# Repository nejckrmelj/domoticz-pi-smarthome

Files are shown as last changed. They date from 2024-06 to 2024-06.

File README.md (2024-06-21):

# Smart Home with Domoticz and Raspberry Pi

## Introduction

This repository is a software and hardware source for a smart home project I was working on during one month of practical training at Erasmus+, at Gut Wehlitz in Schkeuditz, Leipzig, Germany. My mentor Aran Talboys gave me a project to control the relay board with Raspberry Pi and Domoticz. The final version works through MQTT. Raspberry uses docker compose to run three services: Mosquitto MQTT broker, Domoticz smart home system and a python hardware client. Hardware client listens on Domoticz's topic and controls the GPIOs which are connected to relays on the relay board. In the current version GPIOs are not fully synced with Domoticz - if GPIO is changed by some other program, change is not reflected by the hardware client.

## Technologies Used

- **Domoticz** (smart home system)
- **MQTT**
- **Docker**

## Local Setup

Before you start, you need to have a remote GPIO access enabled on your Raspberry Pi (enable it in `sudo raspi-config` settings and with `sudo systemctl enable pigpiod` on your Pi).

To run this repo locally, follow these steps:

1. Clone repository `git clone [repo url]`

2. Move to the software directory `cd software`

3. Copy .env.template file to the .env file and edit variables

4. Build and run app with `docker compose build` and `docker compose up`

5. Go to [http://localhost:8080/](http://localhost:8080/) or [https://localhost:443/](https://localhost:443/)

6. On Domoticz add hardware with type _MQTT Client Gateway with LAN interface_, remote address _mosquitto_ and username and password from you .env file

7. Add new hardware for every useful GPIO on the Raspberry Pi with name _GPIO [pin number]_ and type _Dummy (Does nothing, use for virtual switches only_

8. Add switches with hardware _GPIO [pin number]_ with any type and name

### Clone Repo With Git Sparse Checkout

To clone only specific folder (e.g. on the Rapsberry Pi you only need a software folder) use git sparse: checkout

1. Init repository localy with `git init` and `git remote add origin [repo url]`

2. Init git sparse checkout `git sparse-checkout init --cone`

3. Specify folder to pull `git sparse-checkout set [folder name]`

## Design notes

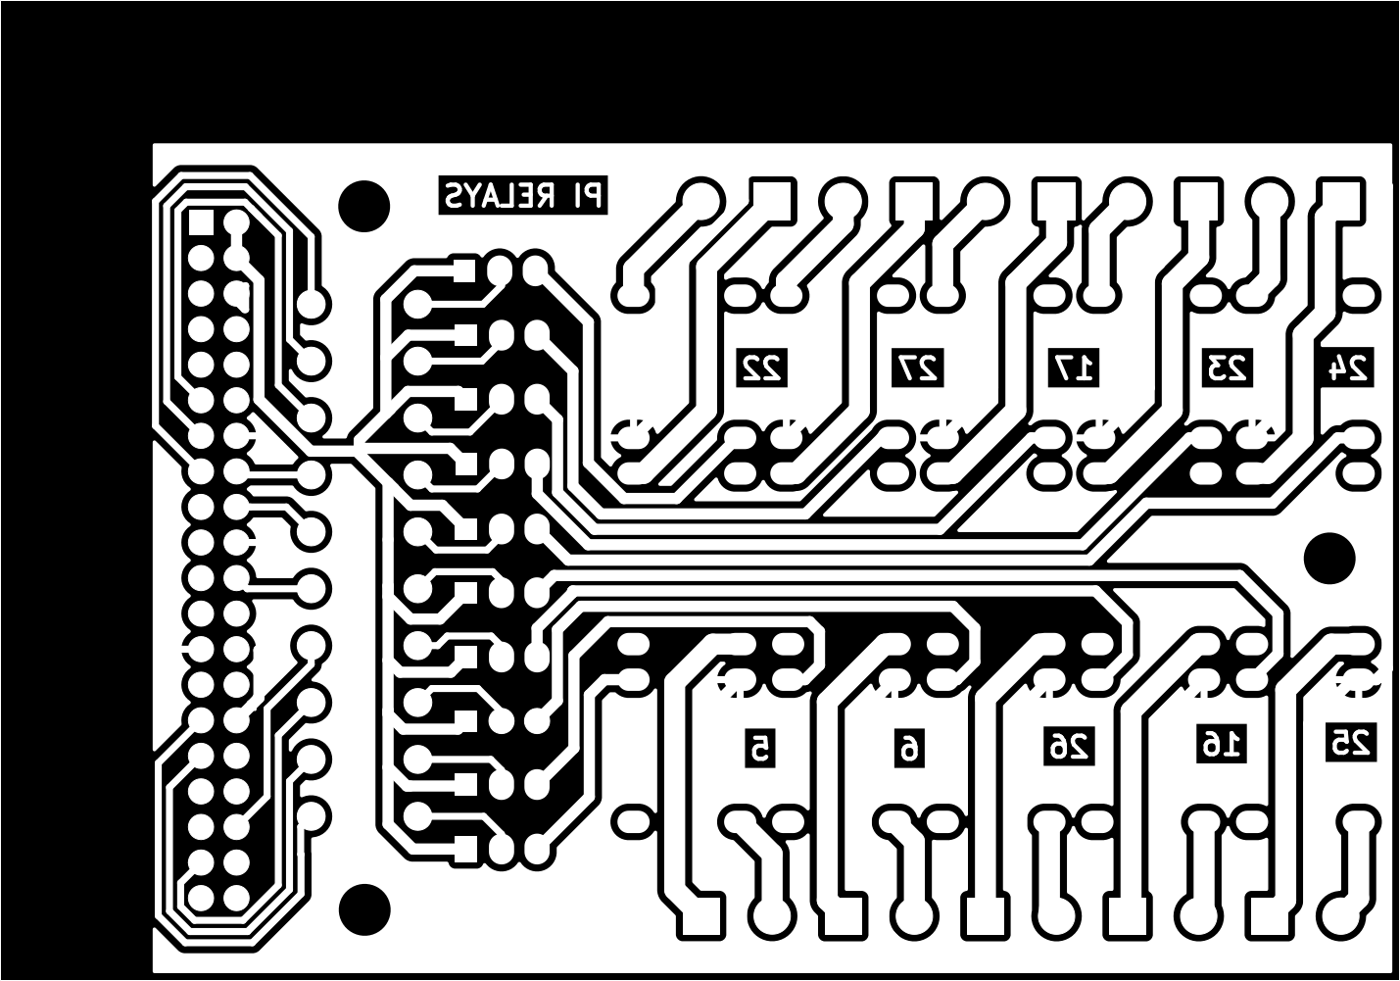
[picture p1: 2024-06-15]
hardware/pi-relay-board/production/relay-board-laser-4.png

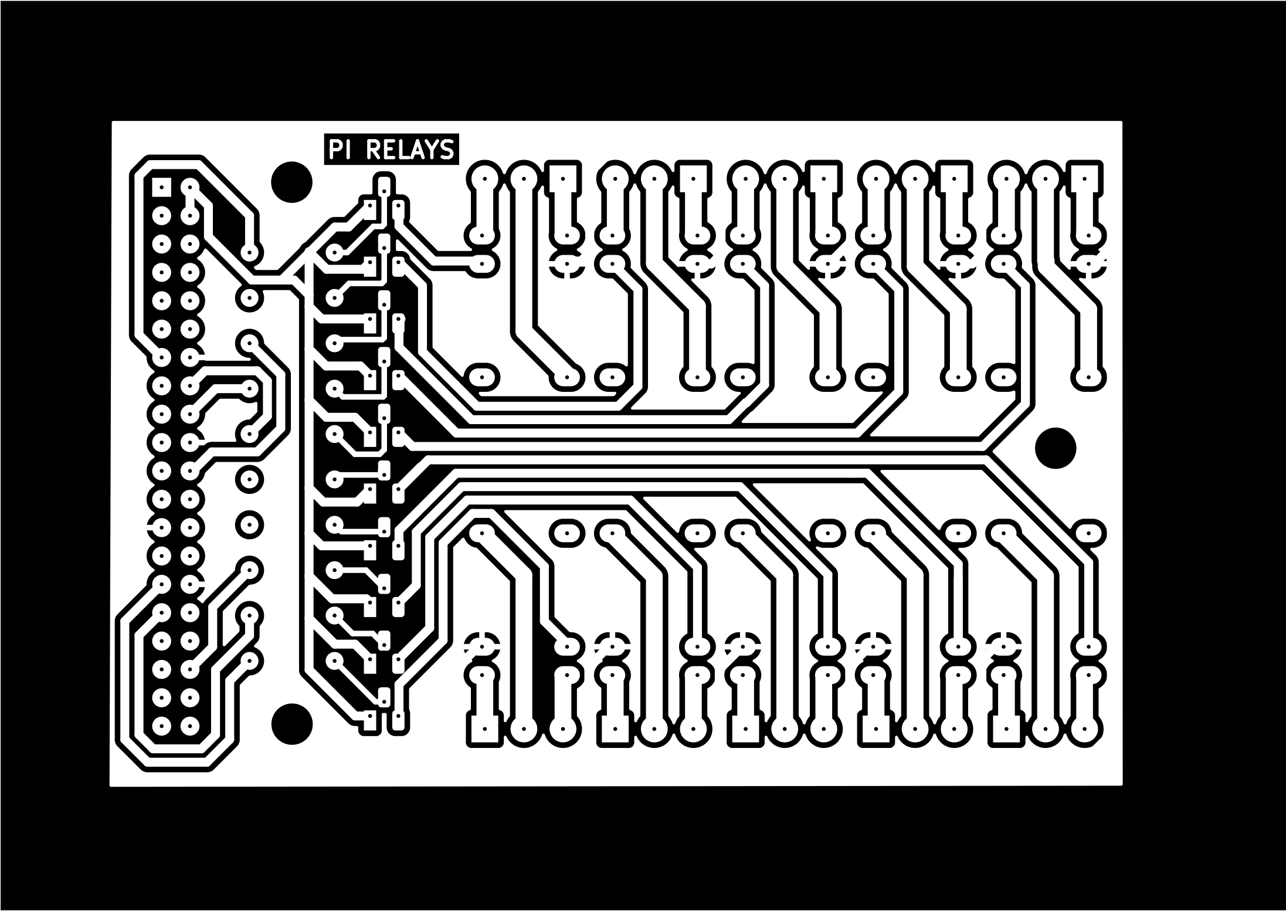
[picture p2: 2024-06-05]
hardware/pi-relay-board/production/relay-board-laser-2.png

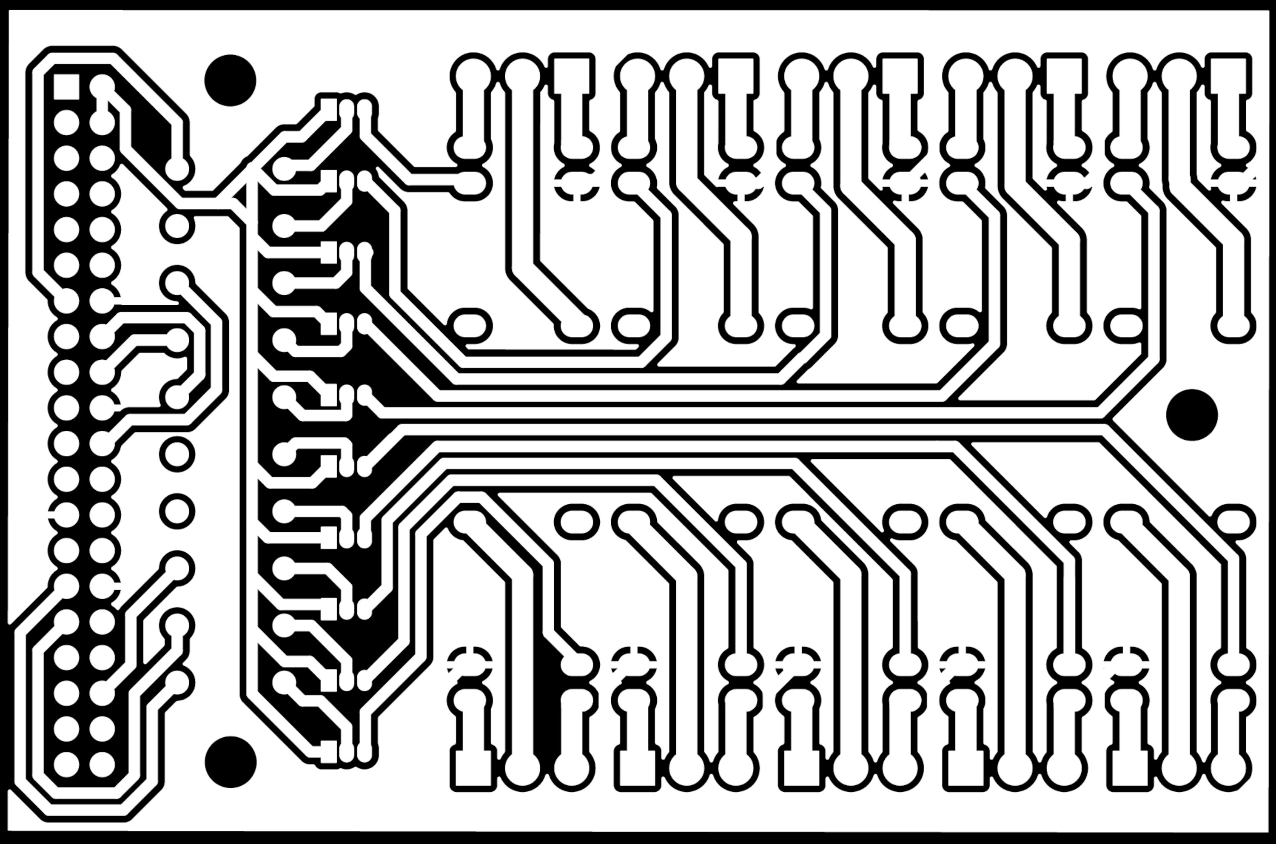
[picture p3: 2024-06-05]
hardware/pi-relay-board/production/relay-board-laser.png

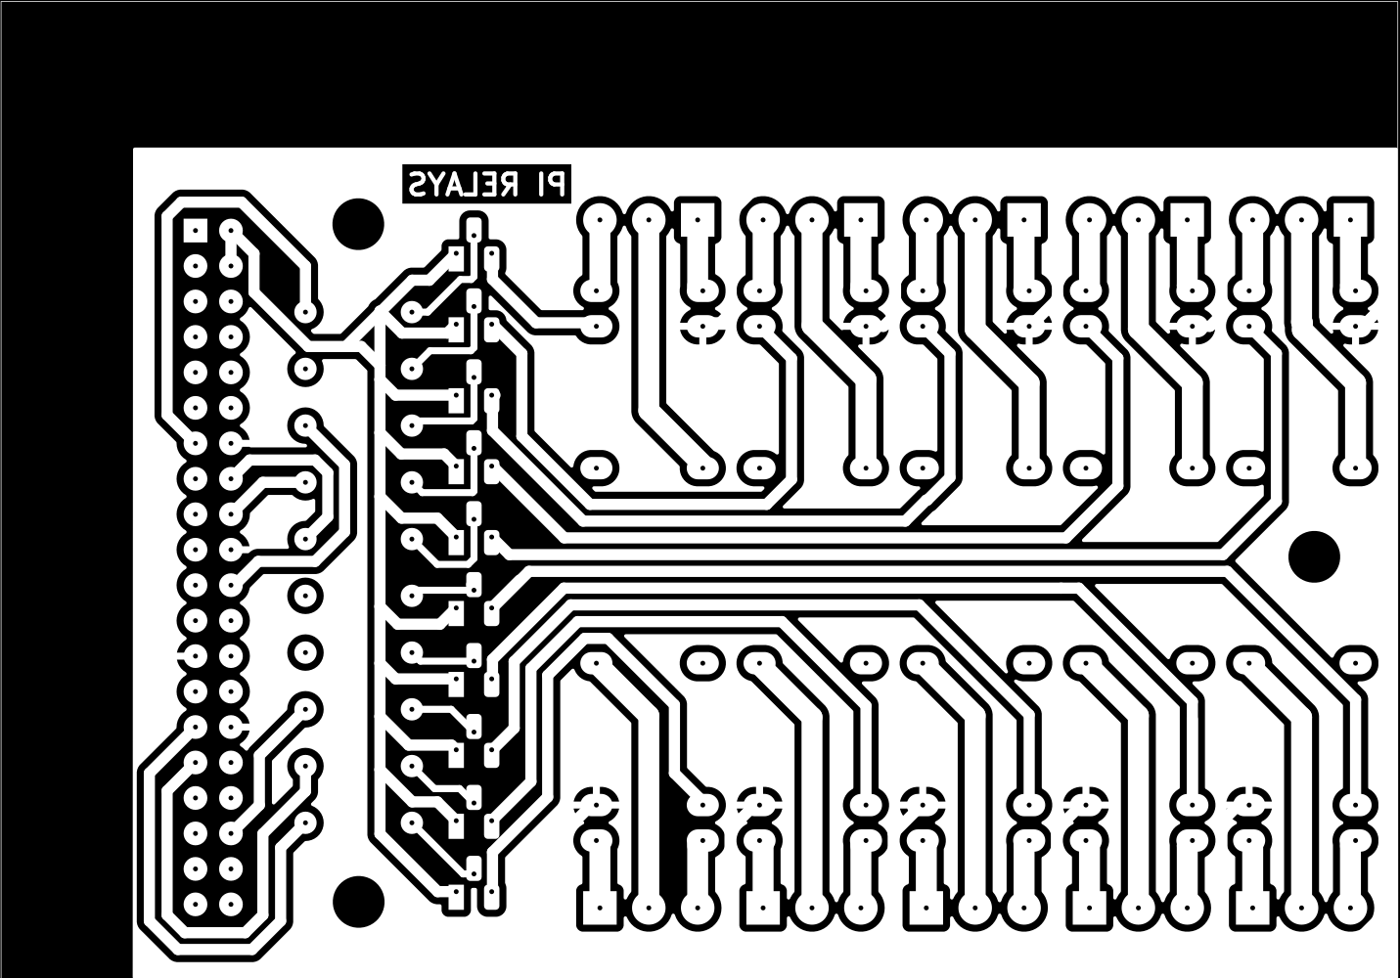
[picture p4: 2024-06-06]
hardware/pi-relay-board/production/relay-board-laser-3.png

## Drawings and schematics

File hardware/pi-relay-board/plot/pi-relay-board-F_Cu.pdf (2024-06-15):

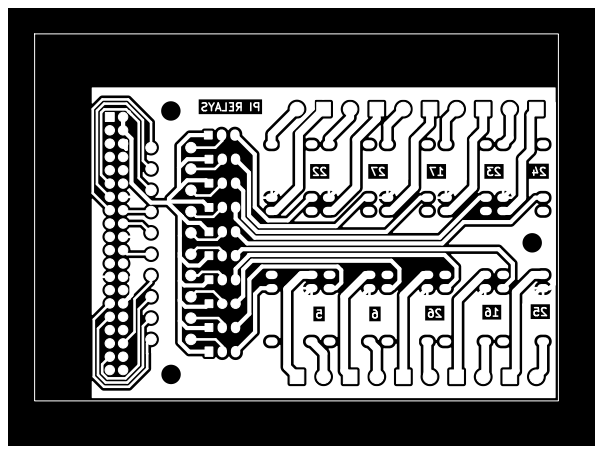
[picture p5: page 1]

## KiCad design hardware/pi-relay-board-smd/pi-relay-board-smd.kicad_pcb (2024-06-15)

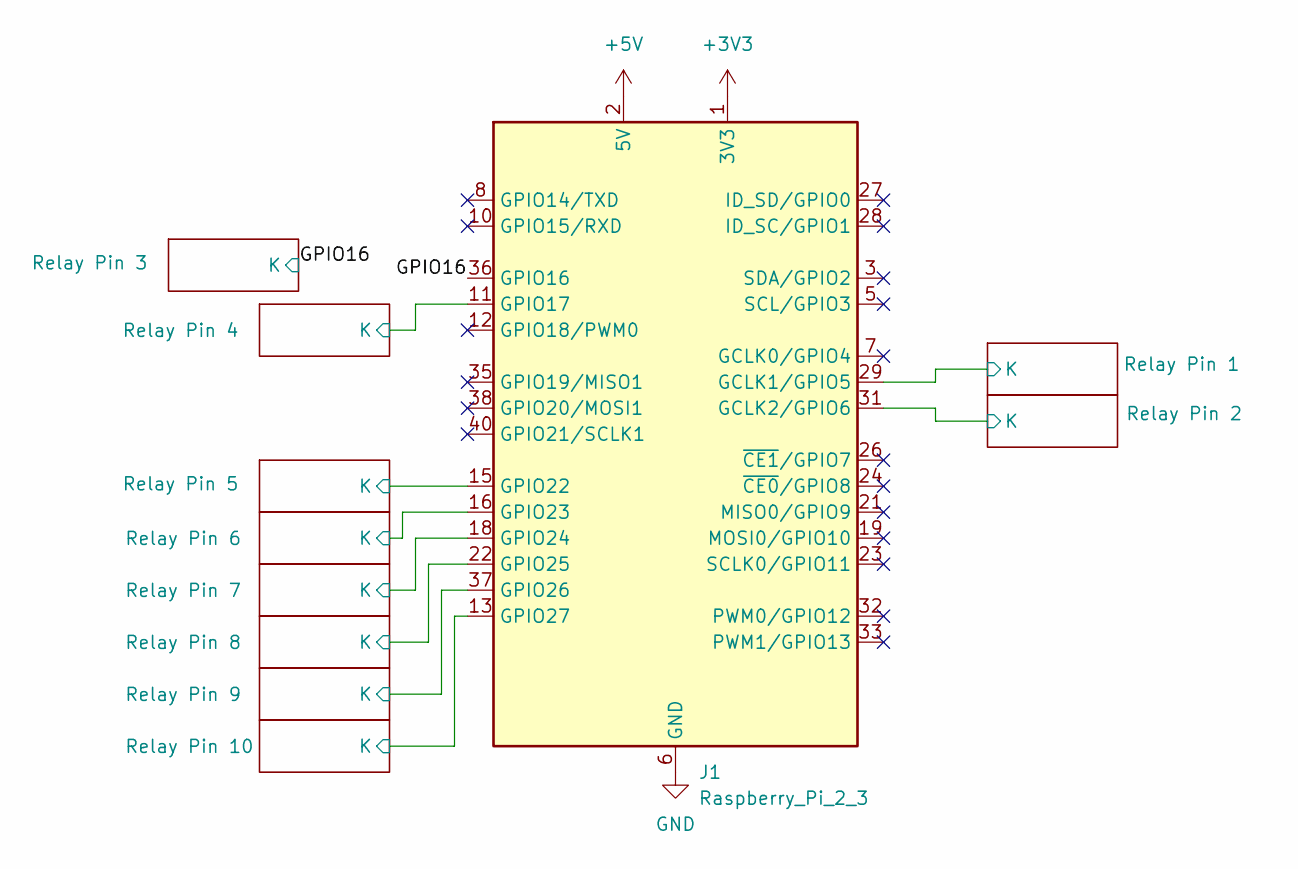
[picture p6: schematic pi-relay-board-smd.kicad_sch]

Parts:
J1: Raspberry_Pi_2_3; PinHeader_2x20_P2.54mm_Vertical_SMD

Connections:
+3V3: J1.1 (3V3), J1.17 (3V3)
+5V: J1.2 (5V), J1.4 (5V); also elsewhere on the board
/GPIO16: J1.36 (GPIO16); also elsewhere on the board
/Relay Pin 1/K: J1.29 (GCLK1/GPIO5); also elsewhere on the board
/Relay Pin 2/K: J1.31 (GCLK2/GPIO6); also elsewhere on the board
/Relay Pin 4/K: J1.11 (GPIO17); also elsewhere on the board
/Relay Pin 5/K: J1.15 (GPIO22); also elsewhere on the board
/Relay Pin 6/K: J1.16 (GPIO23); also elsewhere on the board
/Relay Pin 7/K: J1.18 (GPIO24); also elsewhere on the board
/Relay Pin 8/K: J1.22 (GPIO25); also elsewhere on the board
/Relay Pin 9/K: J1.37 (GPIO26); also elsewhere on the board
/Relay Pin 10/K: J1.13 (GPIO27); also elsewhere on the board
GND: J1.6 (GND), J1.9 (GND), J1.14 (GND), J1.20 (GND), J1.25 (GND), J1.30 (GND), J1.34 (GND), J1.39 (GND); also elsewhere on the board

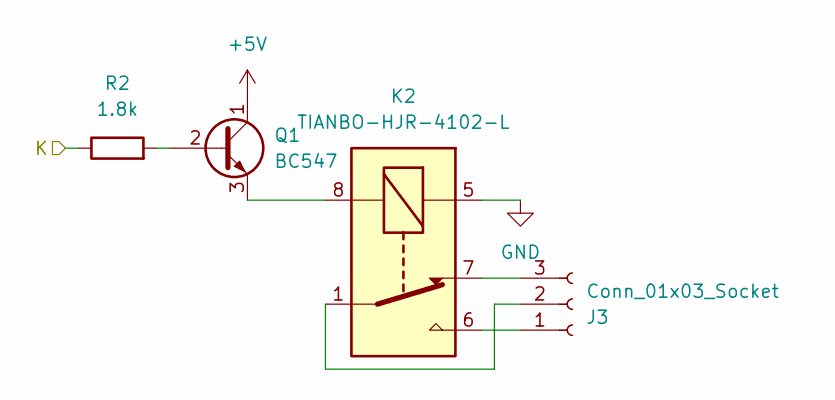
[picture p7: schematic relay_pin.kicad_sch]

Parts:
J3: Conn_01x03_Socket; TerminalBlock_Phoenix_PT-1,5-3-3.5-H_1x03_P3.50mm_Horizontal
K2: TIANBO-HJR-4102-L; Relay_SPDT_HJR-4102
Q1: BC547; SOT-23
R2: 1.8k; R_0805_2012Metric_Pad1.20x1.40mm_HandSolder

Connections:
+5V: Q1.1 (C); also elsewhere on the board
/Relay Pin 2/K: R2.1; also elsewhere on the board
GND: K2.5; also elsewhere on the board
unnamed: J3.1, K2.6
unnamed: J3.2, K2.1
unnamed: J3.3, K2.7
unnamed: Q1.2 (B), R2.2
unnamed: K2.8, Q1.3 (E)

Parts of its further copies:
J2, J4, J5, J6, J7, J8, J9, J10, J11: Conn_01x03_Socket; TerminalBlock_Phoenix_PT-1,5-3-3.5-H_1x03_P3.50mm_Horizontal
K1, K3, K4, K5, K6, K7, K8, K9, K10: TIANBO-HJR-4102-L; Relay_SPDT_HJR-4102
Q2, Q3, Q4, Q5, Q6, Q7, Q8, Q9, Q10: BC547; SOT-23
R1, R3, R4, R5, R6, R7, R8, R9, R10: 1.8k; R_0805_2012Metric_Pad1.20x1.40mm_HandSolder

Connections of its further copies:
+5V: Q2.1 (C), Q3.1 (C), Q4.1 (C), Q5.1 (C), Q6.1 (C), Q7.1 (C), Q8.1 (C), Q9.1 (C), Q10.1 (C); also elsewhere on the board
/GPIO16: R3.1; also elsewhere on the board
/Relay Pin 1/K: R1.1; also elsewhere on the board
/Relay Pin 4/K: R4.1; also elsewhere on the board
/Relay Pin 5/K: R5.1; also elsewhere on the board
/Relay Pin 6/K: R6.1; also elsewhere on the board
/Relay Pin 7/K: R7.1; also elsewhere on the board
/Relay Pin 8/K: R8.1; also elsewhere on the board
/Relay Pin 9/K: R9.1; also elsewhere on the board
/Relay Pin 10/K: R10.1; also elsewhere on the board
GND: K1.5, K3.5, K4.5, K5.5, K6.5, K7.5, K8.5, K9.5, K10.5; also elsewhere on the board
unnamed: J2.1, K1.6
unnamed: J2.2, K1.1
unnamed: J2.3, K1.7
unnamed: J4.1, K3.6
unnamed: J4.2, K3.1
unnamed: J4.3, K3.7
unnamed: J5.1, K4.6
unnamed: J5.2, K4.1
unnamed: J5.3, K4.7
unnamed: J6.1, K5.6
unnamed: J6.2, K5.1
unnamed: J6.3, K5.7
unnamed: J7.1, K6.6
unnamed: J7.2, K6.1
unnamed: J7.3, K6.7
unnamed: J8.1, K7.6
unnamed: J8.2, K7.1
unnamed: J8.3, K7.7
unnamed: J9.1, K8.6
unnamed: J9.2, K8.1
unnamed: J9.3, K8.7
unnamed: J10.1, K9.6
unnamed: J10.2, K9.1
unnamed: J10.3, K9.7
unnamed: J11.1, K10.6
unnamed: J11.2, K10.1
unnamed: J11.3, K10.7
unnamed: Q2.2 (B), R1.2
unnamed: K1.8, Q2.3 (E)
unnamed: Q3.2 (B), R3.2
unnamed: K3.8, Q3.3 (E)
unnamed: Q4.2 (B), R4.2
unnamed: K4.8, Q4.3 (E)
unnamed: Q5.2 (B), R5.2
unnamed: K5.8, Q5.3 (E)
unnamed: Q6.2 (B), R6.2
unnamed: K6.8, Q6.3 (E)
unnamed: Q7.2 (B), R7.2
unnamed: K7.8, Q7.3 (E)
unnamed: Q8.2 (B), R8.2
unnamed: K8.8, Q8.3 (E)
unnamed: Q9.2 (B), R9.2
unnamed: K9.8, Q9.3 (E)
unnamed: Q10.2 (B), R10.2
unnamed: K10.8, Q10.3 (E)

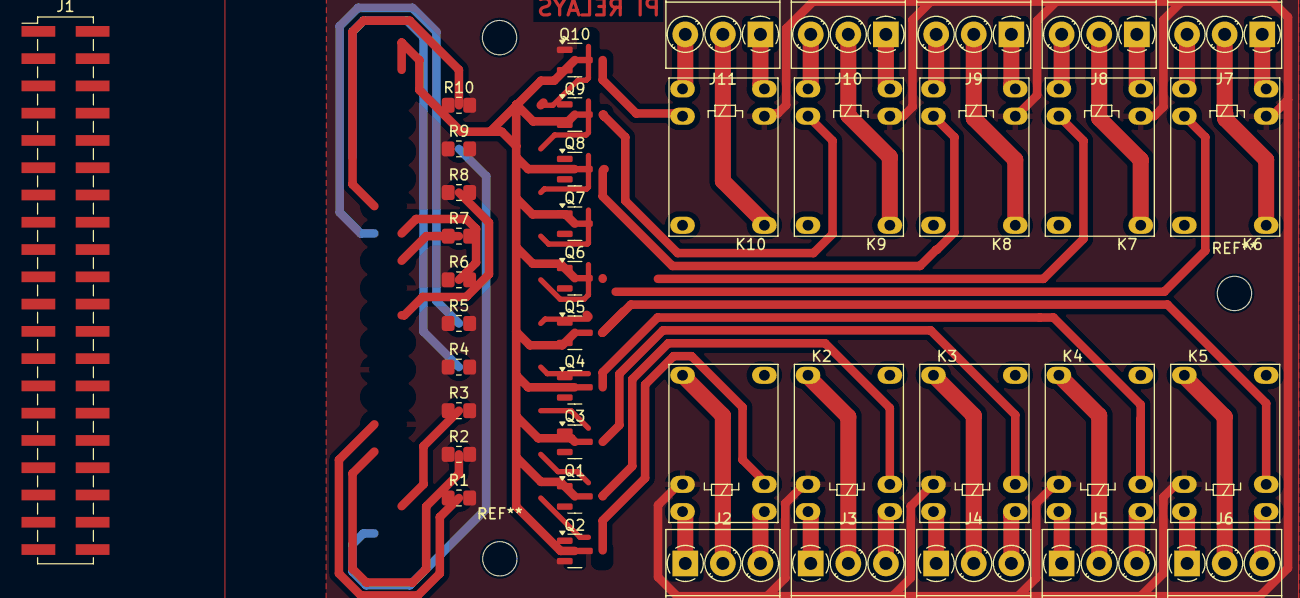
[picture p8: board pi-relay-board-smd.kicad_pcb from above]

Board: 2 copper layers, 41 parts (0 on the bottom side), 63 nets.

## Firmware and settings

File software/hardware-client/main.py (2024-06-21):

import json
import os
import time
import re
from dotenv import load_dotenv
import paho.mqtt.client as mqtt # type: ignore
from gpiozero import LED
import requests

# env variables
load_dotenv()
mqtt_host = os.getenv("MQTT_HOST")
mqtt_port = int(os.getenv("MQTT_PORT"))
mqtt_username = os.getenv("MQTT_USERNAME")
mqtt_password = os.getenv("MQTT_PASSWORD")
domoticz_username = os.getenv("DOMOTICZ_USERNAME")
domoticz_password = os.getenv("DOMOTICZ_PASSWORD")
domoticz_host = os.getenv("DOMOTICZ_HOST")
domoticz_api = f"https://{domoticz_username}:{domoticz_password}@{domoticz_host}/json.htm"

# Get hardware with gpios from domoticz
hardware = {}

def update_hardware():
    global hardware

    print(f"Requesting devices from domoticz: {domoticz_api}")
    try:
        response = requests.post(domoticz_api, verify=False, params={
            "type": "command",
            "param": "getdevices"
        })
        if (response.ok):
            json = response.json()

            for led in hardware.values():
                led.close()

            for device in json["result"]:
                hardware_name = device["HardwareName"]
                status = device["Status"]
                if (device["SwitchType"] == "On/Off" and re.match(r'^GPIO \d+$', hardware_name)):
                    pin = int(hardware_name.split()[1])
                    led = LED(pin)
                    hardware[str(device["HardwareID"])] = led
                    if (status == "On"):
                        led.on()
                    else:
                        led.off()
        else:
            raise Exception(f"Request failed: {response.status_code}, api: {response.url}")
         
    except Exception as e:
        print(f"Update Hardware Error: {e}")
                
update_hardware()
print("Used hardware: ", hardware)

def on_connect(client, userdata, flags, rc, properties):
    print(f"Connected with result code {rc}")
    client.subscribe("domoticz/out")

# Handle incoming messages
def on_message(client, userdata, msg):
    data = json.loads(msg.payload)

    match msg.topic:
        case "domoticz/out":

            if ("switchType" not in data):
                return
            
            try:
                match data["switchType"]:

                    case "On/Off":
                        hardware_idx = data["hwid"]
                        # Check if hardware gpio is initialized
                        if (hardware_idx not in hardware):
                            update_hardware()
                            if (hardware_idx not in hardware):
                                raise Exception(f"Switch with hardware idx {hardware_idx} is missing.")

                        # Switch pin state
                        led = hardware[hardware_idx]
                        led.value = data["nvalue"]
                        print(f"switching pin {led.pin.number} to {led.value}")

            except Exception as e:
                print(f"Error: {e}")


def on_log(client, userdata, level, buf):
    print(f"Log: {buf}")

def on_disconnect(client, userdata, rc):
    if rc != 0:
        print("Unexpected disconnection.")


mqttc = mqtt.Client(mqtt.CallbackAPIVersion.VERSION2)
mqttc.on_connect = on_connect
mqttc.on_message = on_message
# mqttc.on_log = on_log
mqttc.on_disconnect = on_disconnect

# Authentication
mqttc.username_pw_set(mqtt_username, mqtt_password)
# Connect to broker
try:
    print(f"Connecting to broker {mqtt_host}:{mqtt_port}")
    mqttc.connect(mqtt_host, mqtt_port, 60)
except Exception as e:
    print(f"Connection with broker failed: {e}")
    exit(1)

try:
    while True:
        try:
            mqttc.loop(timeout=1.0)

        except Exception as e:
            print(f"Error: {e}")
            time.sleep(5)  # Wait before retrying
            # Reconnect if needed
            try:
                mqttc.reconnect()
            except Exception as e:
                print(f"Reconnection failed: {e}")
                time.sleep(5)

except KeyboardInterrupt:
    print("KeyboardInterrupt caught.")
except Exception as e:
    print(f"Unhandled exception: {e}")
finally:
    print("Exiting...")

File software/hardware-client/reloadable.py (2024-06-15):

# https://medium.com/@jnavarr56/use-file-watching-and-subprocesses-to-develop-python-scripts-with-live-reloading-9ffaa66fd648

from watchdog.observers import Observer
from watchdog.events import FileModifiedEvent, PatternMatchingEventHandler
from threading import Timer
from subprocess import Popen
from sys import argv

# Grab the script name from a command line arg.
SCRIPT_FILENAME = argv[1]


class Runner:
    __proc = None
    __handler_func = None

    # Command to run the passed in script.
    @staticmethod
    def run():
        # Run the python script and keep track of the process.
        Runner.__proc = Popen(["python", SCRIPT_FILENAME])

    # Fires when watched files change.
    @staticmethod
    def handle_file_modified(event):

        # If there is previously running process
        # from a previous reload then kill it.
        if Runner.__proc != None:
            Runner.__proc.kill()

        # Debouncing:

        # If there is a script reload scheduled
        # to occur in the future, cancel it.
        if Runner.__handler_func != None:
            Runner.__handler_func.cancel()

        # Schedule the reload to happen in .5 secs.
        Runner.__handler_func = Timer(1, Runner.run)
        Runner.__handler_func.start()


# Run our passed in script.
Runner.run()

# Initialize file watching object.
file_watcher = Observer()

# Designate our event handler as one that
# activates when any .py files indirectory are changed,
# exluding this one.
file_modified_event_handler = PatternMatchingEventHandler(patterns=["./*.py"], ignore_patterns=["./reloadable.py"])

# Set the action to be taken when the "on_modified" action
# is detected (our debouncing method is called).
file_modified_event_handler.on_modified = Runner.handle_file_modified

# Initialize the file watching.
file_watcher.schedule(file_modified_event_handler, ".", recursive=True)
file_watcher.start()


try:
    while file_watcher.is_alive():
        file_watcher.join(1)
except KeyboardInterrupt:
    file_watcher.stop()

file_watcher.join()

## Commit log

2024-05-29 feat: switched to gpiozero
2024-06-03 feat: project structure, added pcb
    [pi-relay-board.kicad_pcb, pi-relay-board.kicad_sch, relay_pin.kicad_sch]
2024-06-04 hardware: change to tht
    [pi-relay-board.kicad_pcb, pi-relay-board.kicad_sch, relay_pin.kicad_sch]
2024-06-05 feat: pcb bc547 footprint, laser image
    [pi-relay-board.kicad_pcb, pi-relay-board.kicad_sch, relay_pin.kicad_sch]
2024-06-06 fix: laser image scaling
    [pi-relay-board.kicad_pcb]
2024-06-09 feat: CNC drill files
    [pi-relay-board.kicad_pcb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]
2024-06-15 fix: final finishes
    [pi-relay-board-smd.kicad_pcb, pi-relay-board-smd.kicad_sch, pi-relay-board.kicad_pcb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]
